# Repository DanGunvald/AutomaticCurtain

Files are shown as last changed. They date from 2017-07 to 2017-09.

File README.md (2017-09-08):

# AutomaticCurtain

Controls curtain and blinds using servo for blinds and stepper motor for curtain,

Ball puley can be found at : https://www.thingiverse.com/thing:1322

The wallmount/box (curtainmotoholdercontrollerbox.scad) has to be modified so the ballpulley + chain will fit.

Using esp8266 for wifi/mqtt gateway and arduino mini pro for controller. Stepper driver drv8825 is more silent then a4988.

Very basic drawing(automaticcurtain_bb.png) showing how I put it together. Missing all gnd and vcc. Vcc for stepper is 12v, vcc for arduino is 5v and vcc for esp is 3.3v. To control servo power I use a bd237, but that might not be the best choice. I out a rectifier between my 12v source and the stepper driver.

https://www.thingiverse.com/thing:2426076

Materials:<br />
Arduino mini pro  <br />
esp8266 12e (any of the smaller variants if it has to fit in the box)<br />
ams1117 3.3v<br />
5v switching regulator<br />
nema17<br />
sg90 servo <br />
drv8825/a4988 stepper driver<br />
Capcitator<br />
Rectifier(Dont know if this is realy needed)<br />
12v psu<br />

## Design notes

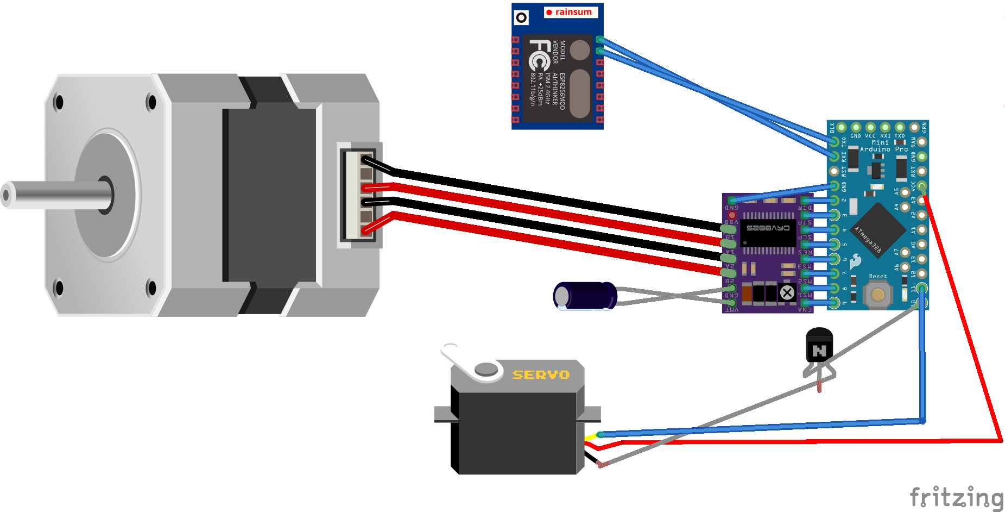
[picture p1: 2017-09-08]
automaticcurtain_bb.png

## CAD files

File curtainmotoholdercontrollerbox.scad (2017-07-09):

d1=20.5; //diameter of ballpulley
ds=3;
sw =31;
w1=42;
h1=25;
mfn=64;
slide=0;
spw=8;
fn1=16; //16
ii=0;
bottomthickness = 4;
sidethickness = 6;
sideheight = 20;
module fd(he) {
  helemets =he;
  esp =[23,24,helemets];
  miniproanddrv = [26,33,helemets];
  drv=[16,21,helemets];
  bec=[23,33,helemets];
  inx=drv[0]+2;
  iny=0;
  hull() {
    translate([-5,70,0]) {
        esp = esp + [2,2,2];
        cube(esp);
    }
    translate([-5,0,0]) {
        bec = bec + [2,2,2];
        cube(bec);
    }
  }
  hull() {
    translate([0,0,0]) {
        bec = bec + [2,2,2];
        cube(bec);
    }
    translate([40,0,0]) {
      drv = drv + [2,2,2];
      miniproanddrv = miniproanddrv + [2,2,2];
      cube(miniproanddrv);
    }
  }
}

mhheight=25;
module motorandelectronicmount(motorheight=25, holes=1) {
  mhheight=motorheight;
  difference() {
    union() {
      minkowski() {
        fd(sideheight);
        cylinder(r=sidethickness,h=0.1,$fn=32);
      }
      translate([12,35,0]) {
        translate([0,2,0]) {
          minkowski() {
            cube([(spw*2)+w1,w1-4,5]);
            cylinder(r=2,h=0.01,$fn=fn1);
          }
        }
        translate([0,12,0]) {
          minkowski() {
            cube([8,25,5]);
            cylinder(r=2,h=0.01,$fn=fn1);
          }
        }
        translate([spw,0,0]) {
          cube([w1,w1+slide,mhheight]);

      }

    }
  }
  if (holes == 1) {
    pp = [9.5,11.5];
    translate([2,-sidethickness,bottomthickness]) {
      cube([pp[0], pp[0], pp[1]]);
    }
    lh = [1.5,11];
    translate([65,34,sideheight-lh[1]]) {
      cube([lh[0], lh[1], 14.2]);
    }
    translate([0,0,bottomthickness]) {
      fd(18);
    }
    translate([12,35,0]) {
      for (x = [0+(spw/2),w1+spw+(spw/2)]) {
        //ii=2;
        ii =(x/2) +3;
        translate([x,(12+12.5) ,0]) {
          translate([0,0,2.1]){
            cylinder(r1=2,r2=4.2,h=3,$fn=fn1);
          }
          cylinder(r=2,h=12,$fn=fn1);
        }
        echo(ii);
         //ii =(x/2) +3;
       }
       translate([spw,0,0]) {
         translate([w1/2,w1/2,0]) {
           hull() {
             cylinder(d=d1,h=h1, $fn=fn1*4);
             translate([0,30,0]) {
               cylinder(d=d1,h=h1,$fn=fn1);
             }
           }
           translate([0,0,h1-3])
           cylinder(d=30,h=3, $fn=fn1*4);
         }
         for (x = [(w1-sw)/2, (w1-sw)/2 + sw]) {

           for (y = [(w1-sw)/2, (w1-sw)/2 + sw]) {
             translate([x, y, 0]) {
               translate([0,slide/2,0]) {
                 cylinder(d=7,h=6,$fn=fn1);
               }
               hull() {
                 cylinder(d=ds,h=h1, $fn=fn1*4);
               }
               translate([0,0,5]) {
                 hull() {
                   cylinder(d=7,h=14, $fn=fn1*4);
                 }
               }
             }
           }
         }
       }
    }
}
  }
}
module mh() {
  difference() {
    #union() {
    }


 }
}
motorandelectronicmount(motorheight=25,holes=1);
translate([-100,0,0]) {
  difference() {
    translate([0,0,sideheight]) {
      minkowski() {
        fd(2.5);
        difference() {
          sphere(r=sidethickness,h=0.1,$fn=32);
          translate([0,0,-sidethickness]) {
            cylinder(r=sidethickness+1, h=sidethickness);
          }
        }
      }
    }
    motorandelectronicmount(motorheight=35,holes=1);
  }
}

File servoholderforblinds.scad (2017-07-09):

outer = [28,24.5,22];
softcorner=3;
servo=[23,12.4,23];

difference() {
    translate([0,softcorner/2,softcorner/2]) {
        minkowski() {
            cube(outer-[0,softcorner,softcorner]);
            rotate([0,90,0]) {
                cylinder(d=softcorner,h=0.1,$fn=16);
            }
        }
    }
    translate([0,(outer[1] - servo[1]) /2,0]) {
        #cube(servo);
    }
}

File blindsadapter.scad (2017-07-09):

d1=4.4;
d2= 3;
t=2;
hei=20;
aw=4.3;
al=12+((d1+(t*2))/3);
at=2.1;
hole=8.8;


difference() {
    union() {
        cylinder(d=d1+(t*2), h=hei, $fn=64);
        translate([-(d1+(t*2))/2, -(d1+(t*2))/2,0]) {
            cube([d1+(t*2),al,t*2]);
        }
    }
    rotate([0,0,105]) {
        difference() {
            cylinder(d=d1, h=hei,$fn=16);
            translate([-d1/2,d1/4,0]) {
                cube([d1,d1,hei]);
            }
        }
    }
  
    translate([0,0,(at/2)+t/2]) {  
        cube([aw,100,at], center=true);
        cube([100,aw,at], center=true);
    }
    translate([0,hole,0]) {
        cylinder(d=2.5,h=10,$fn=16);
    }
    translate([0,0,1]) {
        cube([aw*2,aw*2,3],center=true);
        cylinder(d=7.6,h=at);
    }
}

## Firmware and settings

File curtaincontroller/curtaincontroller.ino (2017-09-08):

#include <Button.h>
#include <EEPROM.h>

//#define DEBUG 1

volatile long curpos = 0;
volatile long curservopos = 0;
volatile bool gotopos = false;
volatile bool sleeping = true;
volatile long wantedpos = 0;
volatile long wantedservopos = 0;
static char serbuffer[64];
static int serbufferpos = 0;
long pendingwantedpos = -1;
long pendingwantedservopos = -1;
long startupdelay = 200;
int direction = 0;
volatile bool servoPulse = false;
volatile bool servoPreHeat = false;
volatile int ss =  0;
long ldummy;
int stepsprsspeed = 10;
long actualstepsthisrun = 0;
long lastsetocr = 0;
long delta = 0;


#define DIR 2
#define STEP 3
#define SLEEP 4
//ative low
#define RESET 5
//active low
#define MS3 6
#define MS2 7
#define MS1 8
#define ENABLE 9
//active low
#define SRVENABLE 10
#define SERVO 11
#define SERVOTOTAL 40000
#define SERVOMIN 1000
#define SERVOMAX 5000
#define SERVOSTEPS 180
#define SERVOSTART 3000

volatile int servoIntPos = SERVOTOTAL -SERVOSTART;
volatile int servoIntPos1 = SERVOSTART;
volatile int maxspeed = 255;
int servopos0 = 1000;
int servopos180 = 5000;
int servostep = (SERVOMAX - SERVOMIN) / SERVOSTEPS;


struct settings {
  int directionstepper;
  int ms1;
  int ms2;
  int ms3;
  long steps;
  long skipstepsonstartfromzero;
  long servoup;
  long servodown;
  long servopredelay;
  long servopostdelay;
  int autoservo;
  long servomovedelay;
  int maxspeedup;
  int maxspeeddown;
};

settings sets;

void loadDefaults() {
    sets.steps = 65000;
    sets.skipstepsonstartfromzero = 200;
    sets.directionstepper = 1;
    sets.ms1 = 1;
    sets.ms2 = 1;
    sets.ms3 = 1;
    sets.servoup = 120;
    sets.servodown = 60;
    sets.servopredelay=200;
    sets.servopostdelay=700;
    sets.autoservo=1;
    sets.servomovedelay=2;
    sets.maxspeedup = 40;
    sets.maxspeeddown = 35;
}

void ReedEeprom() {
  if (EEPROM[0] == 255 && EEPROM[1] == 255) {
    loadDefaults();
    //assume uninitialzed
    StoreEeprom();
    Serial.println("initializing eeprom");
  } else {
    EEPROM.get(0, sets);
  }
}

void StoreEeprom() {
  EEPROM.put(0, sets);
  return;
}

ISR(TIMER2_COMPA_vect){
 if (direction != 0 && curpos != wantedpos && gotopos) {
    curpos += direction;
    actualstepsthisrun ++;
    digitalWrite(STEP, HIGH);
    digitalWrite(STEP, LOW);
    delta = abs(curpos - wantedpos);
    if (delta <= stepsprsspeed*(255-maxspeed)) {
      //slowdown
      lastsetocr = 255 - (delta / stepsprsspeed);
      if (lastsetocr > 255) {
        lastsetocr =255;
      }
      if (lastsetocr < maxspeed) {
        lastsetocr = maxspeed;
      }
      OCR2A = lastsetocr;
    } else {
      if (lastsetocr != maxspeed) {
        if ((actualstepsthisrun / stepsprsspeed) > 255- maxspeed) {
          
          lastsetocr = maxspeed;
           if (lastsetocr > 255) {
            lastsetocr =255;
          }
          OCR2A = lastsetocr;
        } else {
          lastsetocr = 255 - (actualstepsthisrun / stepsprsspeed);
           if (lastsetocr > 255) {
            lastsetocr =255;
          }
          OCR2A = lastsetocr;
        }
      }
    }
  }
}


void DebugPrint() {
return;
  Serial.print("direction:");
  Serial.println(direction);
    Serial.print("curpos:");
  Serial.println(curpos);
    Serial.print("wantedpos:");
  Serial.println(wantedpos);
}
void gotoPos(long dummy, bool move = false) {
  if (dummy >= 0 && dummy <= sets.steps) {
    if (gotopos) {
#ifdef DEBUG
    Serial.println("allready going");
#endif
      //active
      pendingwantedpos = dummy;
    } else {
#ifdef DEBUG
    Serial.print("Going to");
    Serial.println(dummy);
#endif
      if (curpos == 0 && dummy > sets.skipstepsonstartfromzero) {
        curpos = sets.skipstepsonstartfromzero;
      } 
      wantedpos = dummy;

      if (wantedpos != curpos) {
        actualstepsthisrun = 0;
        //wantedpos = dummy;
        if (wantedpos > curpos) {
          //going down
          maxspeed = sets.maxspeeddown;
          SetDirection(0);
          direction = 1;
        } else {
          maxspeed = sets.maxspeedup;
          SetDirection(1);
          direction = -1;
          //going up
        }
        if (sleeping) {
          wakeUp();
          sleeping = false;
        }
        gotopos = true;
      } else {
#ifdef DEBUG
        Serial.println("alleready here");
#endif
      }
    }
  } else {
  //  Serial.println("not going");
  }
}

long changeservoposcountdown = -1;
int tmpS = 0;
bool servoSleep = true;
long servoStarted = -1;
ISR(TIMER1_COMPA_vect){
  if (servoPulse) {
    servoPulse = false;
    OCR1A = servoIntPos1;
    digitalWrite(SERVO, HIGH);
  } else {
    servoPulse = true;
    OCR1A = servoIntPos;
    digitalWrite(SERVO, LOW);
    if (curservopos != wantedservopos) {
      if (servoSleep) {
        digitalWrite(SRVENABLE, HIGH);
        servoStarted = millis();
        servoPreHeat = true;
        servoSleep = false;
      } else {
        if (servoPreHeat) {
          if (servoStarted + sets.servopredelay < millis()) {
            servoPreHeat = false;  
          }
        } else {
          changeservoposcountdown --;
          if (changeservoposcountdown <= 0) {
            if (curservopos < wantedservopos) {
              curservopos ++;
            } else if (curservopos > wantedservopos) {
              curservopos --;
            }
            tmpS = (curservopos * servostep);
            servoIntPos = (SERVOTOTAL - SERVOMIN) - (tmpS);
            servoIntPos1 = SERVOMIN + tmpS;
            changeservoposcountdown = sets.servomovedelay;
          }
        }
      }
    }
  }
}

void setServoPos(long pos) {
  wantedservopos = pos;
  changeservoposcountdown = sets.servomovedelay;
//  printstatus(2);
}

void setupTimerInterruptForStepper() {
  cli();
  TCCR2A = 0;// set entire TCCR0A register to 0
  TCCR2B = 0;// same for TCCR0B
  TCNT2  = 0;//initialize counter value to 0
  // set compare match register for 2khz increments
  OCR2A = 255;// = (16*10^6) / (2000*64) - 1 (must be <256)
  // turn on CTC mode
  TCCR2A |= (1 << WGM21);
  // Set CS01 and CS00 bits for 64 prescaler
  TCCR2B |=  (1 << CS22) ;   
  // enable timer compare interrupt
  TIMSK2 |= (1 << OCIE2A);
  sei();
}

void setupTimerInterruptForServo() {
  //set timer1 interrupt at 1Hz
  TCCR1A = 0;// set entire TCCR1A register to 0
  TCCR1B = 0;// same for TCCR1B
  TCNT1  = 0;//initialize counter value to 0
  // set compare match register for 1hz increments
  OCR1A = 40000;// = (16*10^6) / (1*1024) - 1 (must be <65536)
  // turn on CTC mode
  TCCR1B |= (1 << WGM12);
  // Set CS12 and CS10 bits for 8 prescaler
  TCCR1B |=   (1 << CS11);  ;  
  // enable timer compare interrupt
  TIMSK1 |= (1 << OCIE1A);
  sei();
}

void SetDirection(int wanteddirection) {
  if (sets.directionstepper == 1) {
    if (wanteddirection == 1) {
      //guino down
      digitalWrite(DIR, HIGH);
    } else {
      digitalWrite(DIR, LOW);
    }
  } else {
    if (wanteddirection == 1) {
      //guino down
      digitalWrite(DIR, LOW);
    } else {
      digitalWrite(DIR, HIGH);
    }
  }
}

void setup() {
  Serial.begin(115200);
  ReedEeprom();
  pinMode(SERVO, OUTPUT);
  pinMode(SERVO, OUTPUT);
  pinMode(SRVENABLE, OUTPUT);
  digitalWrite(SRVENABLE,LOW);
  digitalWrite(SERVO, LOW);
  pinMode(12, OUTPUT);
  pinMode(13, OUTPUT);
  digitalWrite(13, LOW);
  digitalWrite(12, LOW);
  pinMode(DIR, OUTPUT);
  pinMode(STEP, OUTPUT);
  pinMode(SLEEP, OUTPUT);
  pinMode(RESET, OUTPUT);
  pinMode(MS3, OUTPUT);
  pinMode(MS2, OUTPUT);
  pinMode(MS1, OUTPUT);
  pinMode(ENABLE, OUTPUT);
  digitalWrite(DIR, LOW);
  digitalWrite(STEP, LOW);
  digitalWrite(SLEEP, LOW);
  digitalWrite(RESET, LOW);
  if (sets.ms1 == 0) {
    digitalWrite(MS1, LOW);
  } else {
    digitalWrite(MS1, HIGH);
  }
  if (sets.ms2 == 0) {
    digitalWrite(MS2, LOW);
  } else {
    digitalWrite(MS2, HIGH);
  }
  if (sets.ms3 == 0) {
    digitalWrite(MS3, LOW);
  } else {
    digitalWrite(MS3, HIGH);
  }
  digitalWrite(ENABLE, LOW);
  gotoSleep();
  setupTimerInterruptForServo();
  setupTimerInterruptForStepper();
  printstatus(3);
}

void wakeUp() {
  digitalWrite(ENABLE, LOW);
  digitalWrite(SLEEP, HIGH);
  digitalWrite(RESET, HIGH);
  digitalWrite(13, HIGH);
  delay(100);
#ifdef DEBUG
  Serial.println("wakeup");
#endif
}

void printstatus(int i) {
  if (i & 1) {
    Serial.print("curpos:");
    Serial.println(curpos);
    
  }
  if (i & 2) {  
     
     delay(120);
    Serial.print("curservopos:");
    Serial.println(curservopos);
  }
 
  if (i & 4) {   
        delay(120);
  
    Serial.print("wantedservopos:");
    Serial.println(wantedservopos);
  }
  if (i & 8) {
    delay(120);
    Serial.print("wantedpos:");
    Serial.println(wantedpos);
  }
  
}


void printvalues() {
  Serial.print("curpos:");
  Serial.println(curpos);
  delay(120);
  Serial.print("steps:");
  Serial.println(sets.steps);
  delay(120);
  Serial.print("skipstepsonstartfromzero:");
  Serial.println(sets.skipstepsonstartfromzero);
  delay(120);
  Serial.print("directionstepper:");
  Serial.println(sets.directionstepper);
  delay(120);
  Serial.print("ms1:");
  Serial.println(digitalRead(MS1));
  delay(120);
  Serial.print("ms2:");
  Serial.println(digitalRead(MS2));
  delay(120);
  Serial.print("ms3:");
  Serial.println(digitalRead(MS3));
  delay(120);
  Serial.print("servouppos:");
  Serial.println(sets.servoup);
  delay(120);
  Serial.print("servodownpos:");
  Serial.println(sets.servodown);
  delay(120);
  Serial.print("servopredelay:");
  Serial.println(sets.servopredelay);
  delay(120);
  Serial.print("servopostdelay:");
  Serial.println(sets.servopostdelay);
  delay(120);
  Serial.print("autoservo:");
  Serial.println(sets.autoservo);
  delay(120);
  Serial.print("servomovedelay:");
  Serial.println(sets.servomovedelay);
  delay(120);
  Serial.print("maxspeedup:");
  Serial.println(sets.maxspeedup);
  delay(120);
  Serial.print("maxspeeddown:");
  Serial.println(sets.maxspeeddown);
  
}

void gotoSleep() {
  lastsetocr = 255;
  OCR2A = 255;
  delay(100);
  //digitalWrite(ENABLE, HIGH);
  digitalWrite(SLEEP, LOW);
  digitalWrite(RESET, HIGH);
  digitalWrite(13, LOW);
  //printstatus(1);
#ifdef DEBUG
  Serial.println("Sleep");
#endif
}





void settings(char *strbuf) {
    String str = strbuf;
    String key = str.substring(0,str.indexOf(':'));
    String value = str.substring(str.indexOf(':') + 1);
    if (key.length() > 0 && value.length() > 0 ) {
      long val = value.toInt();
      if (key == "ms1") {
        if (val == 1 ) {
          digitalWrite(MS1, HIGH);
          sets.ms1 = 1;
        } else {
          digitalWrite(MS1, LOW);
          sets.ms1 = 0;
        }
      }
      if (key == "ms2") {
        if (val == 1 ) {
          digitalWrite(MS2, HIGH);
          sets.ms2 = 1;
        } else {
          digitalWrite(MS2, LOW);
          sets.ms2 = 0;
        }
      }
      if (key == "ms3") {
        if (val == 1 ) {
          digitalWrite(MS3, HIGH);
          sets.ms3 = 1;
        } else {
          digitalWrite(MS3, LOW);
          sets.ms3 = 0;
        }
      }
      if (key =="servomovedelay") {
        if (val >= 0 ) {
          sets.servomovedelay = val;
        }
      }
      if (key == "directionstepper") {
        if (val == 1) {
          sets.directionstepper = 1;
        } else {
          sets.directionstepper = 0;
        }
      }
      if (key == "steps") {
        if (val > 1) {
          sets.steps = val;
        }
      }  
      if (key == "skipstepsonstartfromzero") {
        if (val >= 0) {
          sets.skipstepsonstartfromzero = val;
        }
      }
      if (key ==  "curpos") {
        if (val > -1) {
          curpos = val;
        }
      }
      if (key ==  "maxspeedup") {
        if (val > -1) {
          sets.maxspeedup = val;
        }
      }
      if (key ==  "maxspeeddown") {
        if (val > -1) {
          sets.maxspeeddown = val;
        }
      }
      
      if (key == "servopostdelay") {
        if (val >= 0) {
          sets.servopostdelay = val;
        }
      }
      if (key == "servopredelay") {
        if (val >= 0) {
          sets.servopredelay = val;
        }
      }
      if (key ==  "autoservo") {
        if (val == 0) {
          sets.autoservo = 0;
        } else {
          sets.autoservo = 1;
        }
      }
      if (key ==  "servouppos") {
        if (val >= 0) {
          sets.servoup = val;
        }
      }
      if (key == "servodownpos") {
        if (val >= 0) {
        sets.servodown = val;
      }
    }
  }
}


void commands() {
  if (strncmp(serbuffer, "sethome", 7) == 0) {
    curpos = 0;
  }
      if (strncmp("store", serbuffer, 5) == 0) {
        StoreEeprom();
      }
      if (strncmp("status", serbuffer, 6) == 0) {
        printstatus(3);
      }
      if (strncmp("defaults", serbuffer, 8) == 0) {
        printvalues();
        loadDefaults();
        StoreEeprom(); 
        printvalues();   
      }
      
      if (strncmp("values", serbuffer, 6) == 0) {
        printvalues();
      }
      if (strncmp(serbuffer, "servodown", 9) == 0) {
        setServoPos(sets.servodown);
      }
      if (strncmp(serbuffer, "servoup", 7) == 0) {
        setServoPos(sets.servoup);
      }
      if (strncmp(serbuffer, "down", 4) == 0) {
        if (sets.autoservo) {
          setServoPos(sets.servodown);
        }
        gotoPos(sets.steps);
      }
      if (strncmp(serbuffer, "up", 2) == 0) {
        gotoPos(0,true);
        if (sets.autoservo) {
         setServoPos(sets.servoup);
        }
      }
      if (strncmp(serbuffer, "gotopos:", 8) == 0) {
        String str = serbuffer + 8;
        long dummy = str.toInt();
        gotoPos(dummy);
      }
      if (strncmp(serbuffer, "gotoservopos:", 13) == 0) {
        String str = serbuffer + 13;
        long dummy = str.toInt();
        if (dummy >= 0) {
          setServoPos(dummy);
        }
      }
}

long lastStatus = 0;

void loop() {
  DebugPrint();
  while (Serial.available() > 0) {
    char c = Serial.read();
    if (c == 10 || c == 13) {
      serbuffer[serbufferpos] = 0;
      serbufferpos = 0;
      if (strncmp(serbuffer, "set ", 4) == 0) {
        settings(serbuffer + 4);  
        //set
      } else {
        commands();
      }
    } else {
      serbuffer[serbufferpos++] = c;
    }
    if (serbufferpos > 60) {
      serbufferpos = 0;
    }
  }
  if (gotopos) {
    #ifdef DEBUG
      if (DEBUG > 2) {
        Serial.println(lastsetocr);
      }
    #endif
  }

#ifdef DEBUG
  if (curpos != wantedpos || curservopos != wantedservopos) {
    printstatus(15);
    Serial.println(millis());
        lastStatus = millis();

  }
#endif
  if (lastStatus + 60000 < millis()) {
    printstatus(3);
    lastStatus = millis();
  }
  if (gotopos && wantedpos==curpos) {
    if (pendingwantedpos != -1) {
      gotopos = false;
      gotoPos(pendingwantedpos);
//      wantedpos = pendingwantedpos;
      pendingwantedpos = -1;
      printstatus(3);
    } else {
      gotoSleep();
      gotopos = false;
      sleeping = true;
      printstatus(3);
    }
  }
   if (changeservoposcountdown != -1 && curservopos == wantedservopos) {
    changeservoposcountdown = -1;
    printstatus(3);
    digitalWrite(SRVENABLE, LOW);
    servoSleep = true;
   } 
 }

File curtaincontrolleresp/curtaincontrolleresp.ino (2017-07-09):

#include <ESP8266WiFi.h>
#include <ESP8266mDNS.h>
#include <WiFiUdp.h>
#include <ArduinoOTA.h>
#include <PubSubClient.h>

const char* ssid = "<ssid>";
const char* password = "<password>";
char chipid[12];
#define HOST "CURTAIN-%s"
#define TOPIC "curtain/%s/action"
#define TOPICSTATUS "curtain/%s/status/"
//#define DEBUG_TELNET
const char* mqttserver="<mqttserver>";
char mqtttopic[48] = "";
char mqtttopicstatus[48] = "";
static char serbuffer[64];
static int serbufferpos = 0;

WiFiServer server(80);
WiFiClient client;
PubSubClient mqttclient(client);

#ifdef DEBUG_TELNET
  WiFiServer  telnetServer(23);
  WiFiClient  telnetClient;
#endif

// Macros for debugging
#ifdef DEBUG_TELNET
  #define     DEBUG_PRINT(x)    telnetClient.print(x)
  #define     DEBUG_PRINTLN(x)  telnetClient.println(x)
  #define     DEBUG_PRINTF(x,y)   telnetClient.printf(x,y)
#else
  #define     DEBUG_PRINT(x)    Serial.print(x)
  #define     DEBUG_PRINTLN(x)  Serial.println(x)
  #define     DEBUG_PRINTF(x,y)   Serial.printf(x,y)
#endif


#ifdef DEBUG_TELNET
void handleTelnet(void) {
  if (telnetServer.hasClient()) {
    if (!telnetClient || !telnetClient.connected()) {
      if (telnetClient) {
        telnetClient.stop();
      }
      telnetClient = telnetServer.available();
    } else {
      telnetServer.available().stop();
    }
  }
}
#endif


void setup() {
  char host[64];
  Serial.begin(115200);
#ifdef DEBUG_TELNET
  // start the Telnet server
  telnetServer.begin();
  telnetServer.setNoDelay(true);
#endif
  pinMode(2, OUTPUT);
  
  sprintf(chipid, "%08X", ESP.getChipId());
  sprintf(host, HOST, chipid);
  sprintf(mqtttopic, TOPIC, chipid);
  sprintf(mqtttopicstatus, TOPICSTATUS, chipid);
  WiFi.hostname(host);
  ArduinoOTA.setHostname(host);

  WiFi.mode(WIFI_STA);
  WiFi.begin(ssid, password);
  for (int i = 0; i < 8;i++) {
      digitalWrite(2, HIGH);
      delay(250);
      digitalWrite(2, LOW);
      delay(250);
    }
  while (WiFi.waitForConnectResult() != WL_CONNECTED) {
    for (int i = 0; i < 8;i++) {
      digitalWrite(2, HIGH);
      delay(100);
      digitalWrite(2, LOW);
      delay(100);
    }
    delay(1000);
    ESP.restart();
  }
  digitalWrite(2, LOW);

  ArduinoOTA.onStart([]() {
    Serial.println("Start");
  });
  ArduinoOTA.onEnd([]() {
    Serial.println("End");
  });
  ArduinoOTA.onProgress([](unsigned int progress, unsigned int total) {
    Serial.printf("Progress: %u%%\n", (progress / (total / 100)));
  });
  ArduinoOTA.onError([](ota_error_t error) {
    Serial.printf("Error[%u]: ", error);
    if (error == OTA_AUTH_ERROR) Serial.println("Auth Failed");
    else if (error == OTA_BEGIN_ERROR) Serial.println("Begin Failed");
    else if (error == OTA_CONNECT_ERROR) Serial.println("Connect Failed");
    else if (error == OTA_RECEIVE_ERROR) Serial.println("Receive Failed");
    else if (error == OTA_END_ERROR) Serial.println("End Failed");
  });
  ArduinoOTA.begin();
  mqttclient.setServer(mqttserver, 1883);
  mqttclient.setCallback(mqttcallback);
  digitalWrite(2, HIGH);
}


void mqttcallback(char* topic, byte* payload, unsigned int length) {
  digitalWrite(2, LOW);
  if (strcmp(topic, mqtttopic) == 0) {
      char *s = (char *)malloc(length + 1);
      strncpy(s, (char *)payload, length);
      Serial.println(s);
  }
  digitalWrite(2, HIGH);
}

void mqttreconnect() {
  int numretries = 0;
  while (!mqttclient.connected() && numretries < 3) {
    if (mqttclient.connect(chipid)) {
      mqttclient.subscribe(mqtttopic);
    } else {
      delay(1000);
    }
    numretries ++;
  }
}


char * getSerialData() {
char * result = NULL;
while (Serial.available() > 0) {
    char c = Serial.read();
    if (c == 10 || c== 13) {
      serbuffer[serbufferpos] = 0;
      result = serbuffer;
      serbufferpos = 0;
    } else {
      serbuffer[serbufferpos++] = c;
    }
    if (serbufferpos > 63) {
      serbufferpos = 0;
    }
  }
  return result;
}

long t = 0;
void loop() {
  #ifdef DEBUG_TELNET
  // handle Telnet connection for debugging
  handleTelnet();
#endif
 

  ArduinoOTA.handle();
  char *ser = getSerialData();
  if (ser != NULL) {
    char *s = strstr(ser,":");
    if (s) {
      *s = 0;
      s++;
      String mytopic=mqtttopicstatus;
      mytopic += ser;
      mqttclient.publish(mytopic.c_str(),s);
      
    }
    
    
  }
  if (!mqttclient.connected()) {
    mqttreconnect();
  }

  if (mqttclient.connected()) {
    mqttclient.loop();
  }
  
 
}

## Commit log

2017-07-09 Added openscad files
    [blindsadapter.scad, curtainmotoholdercontrollerbox.scad, servoholderforblinds.scad]
2017-07-11 addded very basic schematic
